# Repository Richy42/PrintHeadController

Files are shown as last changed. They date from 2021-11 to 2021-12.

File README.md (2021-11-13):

# PrintHeadController
A 3D printer controller board

Inspired by the possibility of Klipper 3D printer firmware (https://www.klipper3d.org/ ) that allows to have several I/O controller boards, PrintHeadController is a small board intended to be mounted on the moving print head assembly.

This reduces the cabling effort significantly as only power supply and USB is needed.

PrintHeadController has the following features:
* Based on the RP2040 MCU (the one that is used on the Raspberry PI Pico), so it is supported by the Klipper firmware out of the box
* Single socket for a stepper driver module e.g. DRV8825, various TMC variants
* Supports the SPI configuration of TMC drivers
* 12 V and 24 V capable
* 4 Digital inputs
* 4 MOSFET outputs (e.g. hotend heater, fans)
* 4 Thermistor inputs
* BLTouch support
* Debug pins accessible
* Accelerometer ADXL245 optional on board

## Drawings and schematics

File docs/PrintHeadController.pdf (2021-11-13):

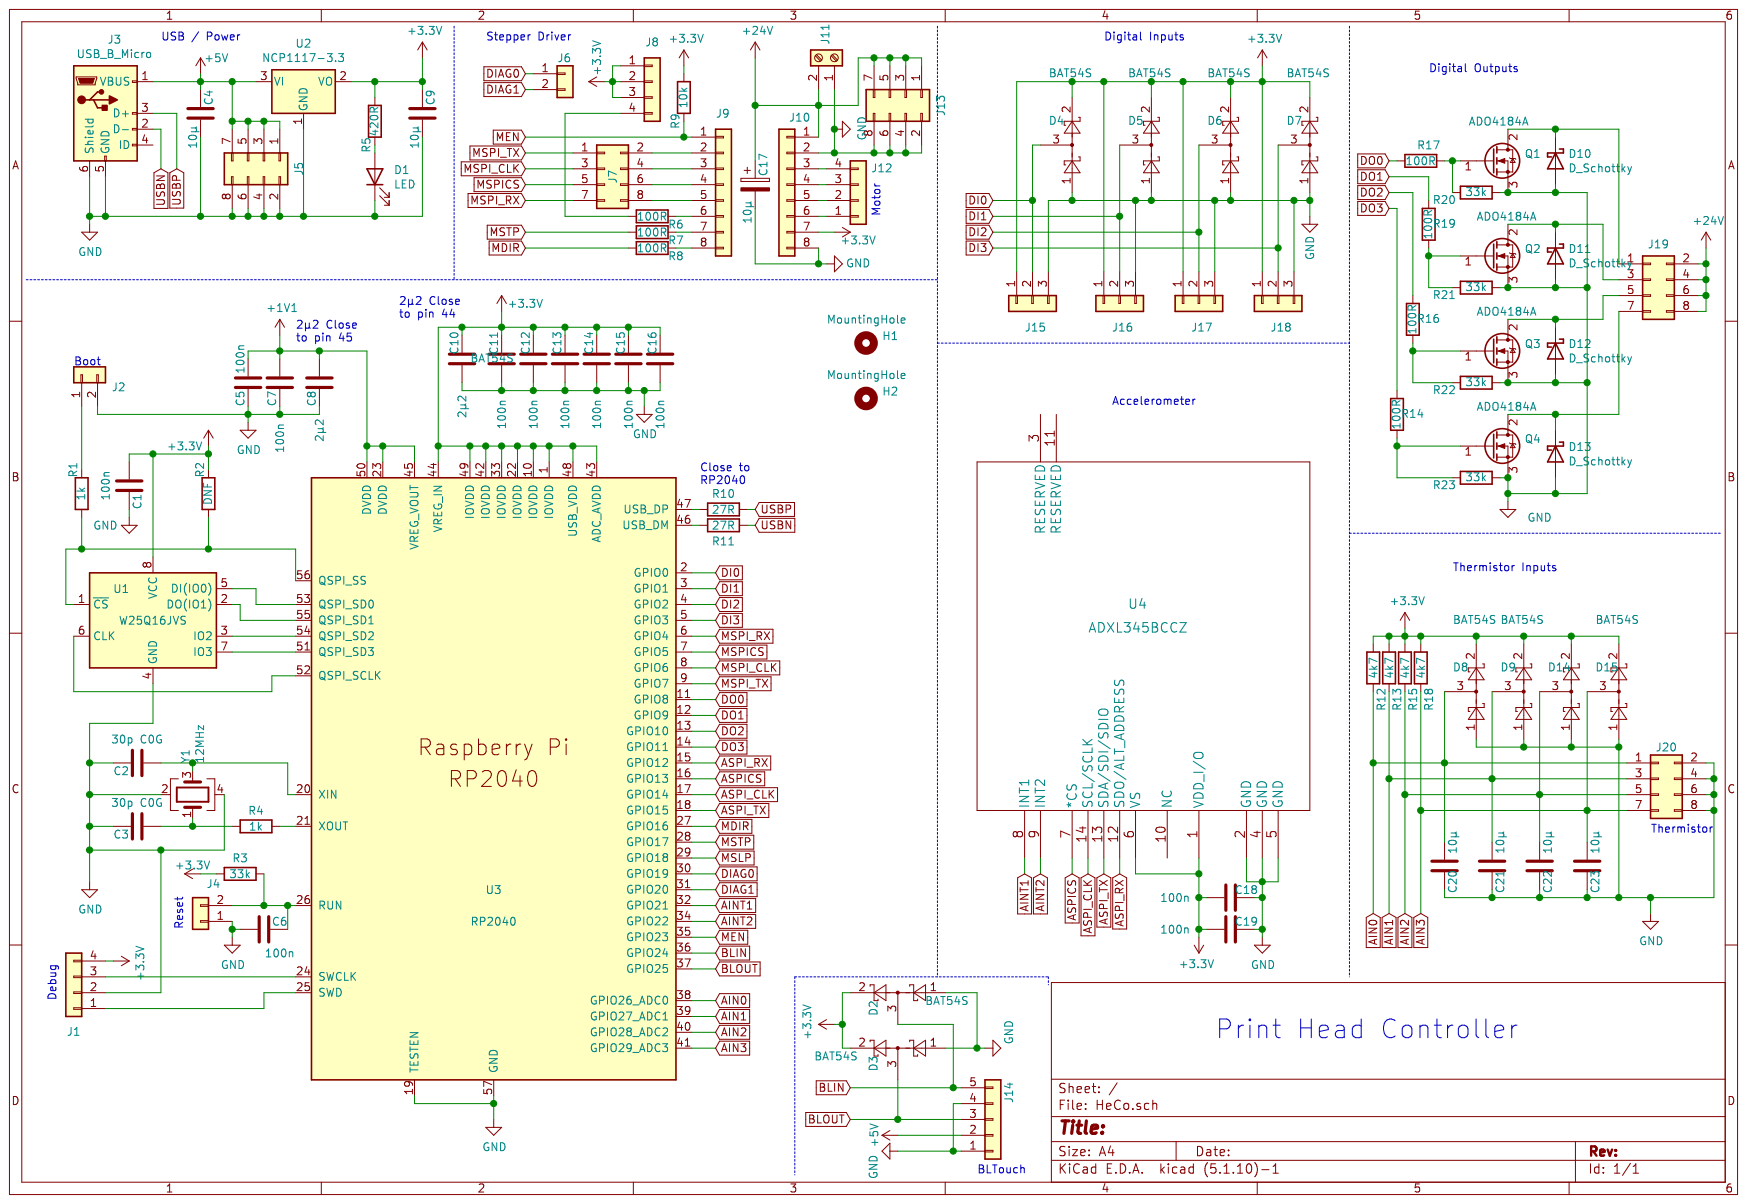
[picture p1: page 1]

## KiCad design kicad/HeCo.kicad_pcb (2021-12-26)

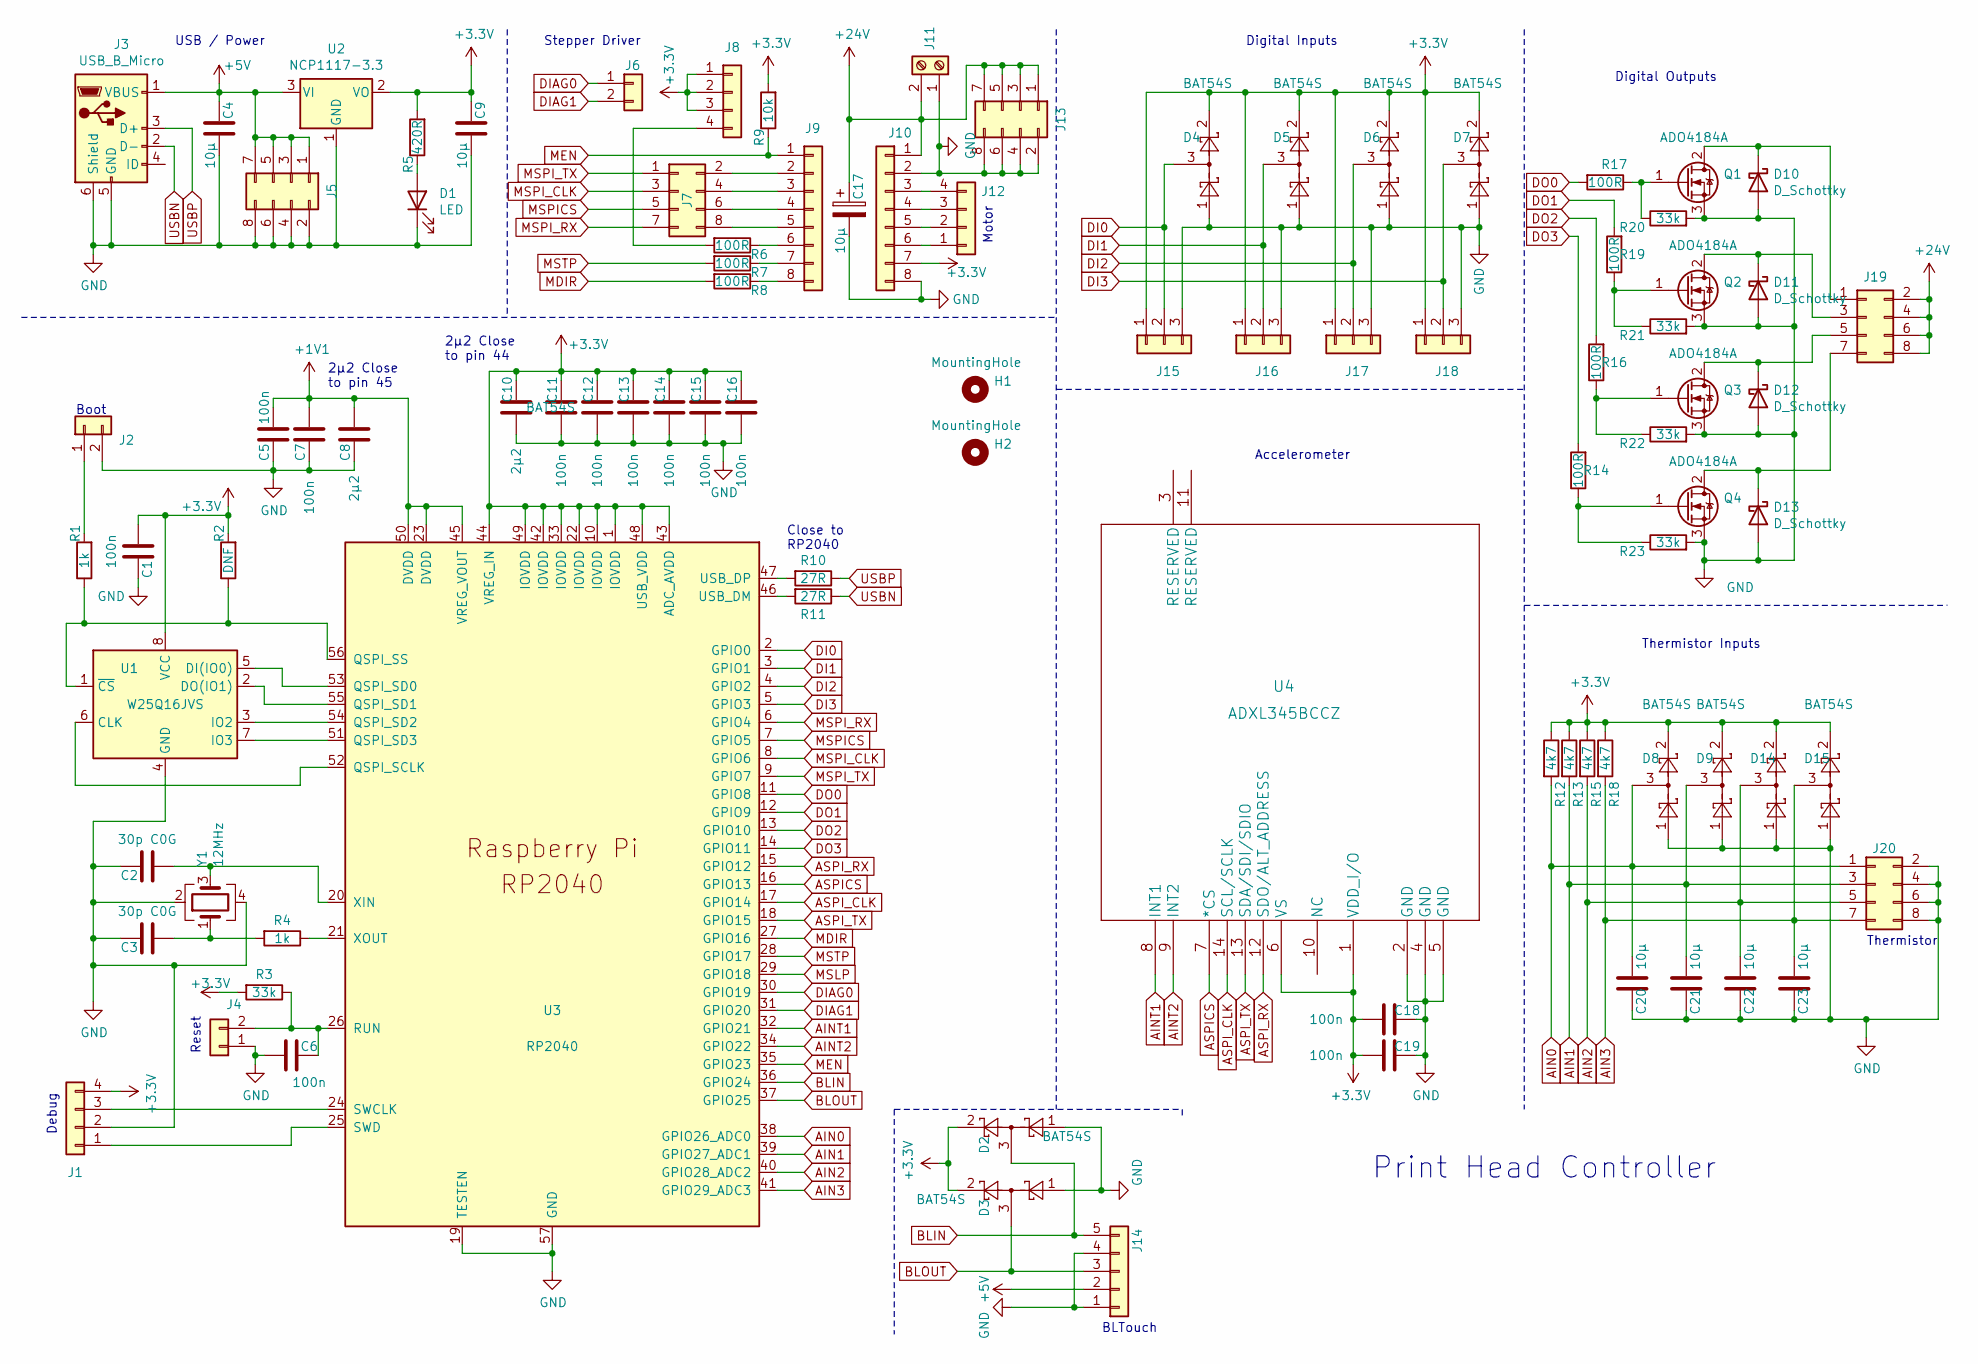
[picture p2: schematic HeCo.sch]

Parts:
C1, C5, C6, C7, C11, C12, C13, C14, C15, C16, C18, C19: 100n; C_0603_1608Metric
C2, C3: 30p C0G; C_0603_1608Metric
C4, C9, C20, C21, C22, C23: 10µ; C_0603_1608Metric
C8, C10: 2µ2; C_0603_1608Metric
C17: 10µ; CP_Elec_4x3
D1: LED; LED_0603_1608Metric
D2, D3, D4, D5, D6, D7, D8, D9, D14, D15: BAT54S; SOT-23
D10, D11, D12, D13: D_Schottky; D_0603_1608Metric
H1, H2: MountingHole; MountingHole_3.2mm_M3
J1, J8, J12: Conn_01x04; PinHeader_1x04_P2.54mm_Vertical
J2, J4: Conn_01x02; PinHeader_1x02_P2.54mm_Vertical
J3: USB_B_Micro; USB_Micro-B_Molex_47346-0001
J5, J7, J13, J19, J20: Conn_02x04_Odd_Even; PinHeader_2x04_P2.54mm_Vertical
J6: Conn_01x02; PinSocket_1x02_P2.54mm_Vertical
J9, J10: Conn_01x08; PinSocket_1x08_P2.54mm_Vertical
J11: Screw_Terminal_01x02; PhoenixContact_MSTBVA_2,5_2-G-5,08_1x02_P5.08mm_Vertical
J14: Conn_01x05; PinHeader_1x05_P2.54mm_Vertical
J15, J16, J17, J18: Conn_01x03; PinHeader_1x03_P2.54mm_Vertical
Q1, Q2, Q3, Q4: ADO4184A; TO-252-2
R1, R4: 1k; R_0603_1608Metric
R2: DNF; R_0603_1608Metric
R3, R20, R21, R22, R23: 33k; R_0603_1608Metric
R5: 420R; R_0603_1608Metric
R6, R7, R8, R14, R16, R17, R19: 100R; R_0603_1608Metric
R9: 10k; R_0603_1608Metric
R10, R11: 27R; R_0603_1608Metric
R12, R13, R15, R18: 4k7; R_0603_1608Metric
U1: W25Q16JVS; SOIC-8_5.23x5.23mm_P1.27mm
U2: NCP1117-3.3; SOT-223-3_TabPin2
U3: RP2040; RP2040-QFN-56
U4: ADXL345BCCZ
Y1: 12MHz; Crystal_SMD_3225-4Pin_3.2x2.5mm

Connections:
+1V1: C5.1, C7.1, C8.1, U3.23 (DVDD), U3.45 (VREG_VOUT), U3.50 (DVDD)
+3V3: C1.1, C9.1, C10.1, C11.1, C12.1, C13.1, C14.1, C15.1, C16.1, C18.2, C19.2, D2.2, D3.2, D4.2, D5.2, D6.2, D7.2, D8.2, D9.2, D14.2, D15.2, J1.4, J8.1, J8.2, J8.3, J10.7, J15.1, J16.1, J17.1, J18.1, R2.2, R3.2, R5.2, R9.2, R12.1, R13.1, R15.1, R18.1, U1.8 (VCC), U2.2 (VO), U3.1 (IOVDD), U3.10 (IOVDD), U3.22 (IOVDD), U3.33 (IOVDD), U3.42 (IOVDD), U3.43 (ADC_AVDD), U3.44 (VREG_IN), U3.48 (USB_VDD), U3.49 (IOVDD), U4.1 (VDD_I/O), U4.6 (VS)
+5V: C4.1, J3.1 (VBUS), J5.1, J5.3, J5.5, J5.7, J14.2, U2.3 (VI)
+24V: C17.1, J10.1, J11.2, J13.1, J13.3, J13.5, J13.7, J19.2, J19.4, J19.6, J19.8
AIN0: C20.1, D8.3, J20.1, R12.2, U3.38 (GPIO26_ADC0)
AIN1: C21.1, D9.3, J20.3, R13.2, U3.39 (GPIO27_ADC1)
AIN2: C22.1, D14.3, J20.5, R15.2, U3.40 (GPIO28_ADC2)
AIN3: C23.1, D15.3, J20.7, R18.2, U3.41 (GPIO29_ADC3)
AINT1: U3.32 (GPIO21), U4.8 (INT1)
AINT2: U3.34 (GPIO22), U4.9 (INT2)
ASPICS: U3.16 (GPIO13), U4.7 (*CS)
ASPI_CLK: U3.17 (GPIO14), U4.14 (SCL/SCLK)
ASPI_RX: U3.15 (GPIO12), U4.12 (SDO/ALT_ADDRESS)
ASPI_TX: U3.18 (GPIO15), U4.13 (SDA/SDI/SDIO)
BLIN: D2.3, J14.5, U3.36 (GPIO24)
BLOUT: D3.3, J14.3, U3.37 (GPIO25)
DI0: D4.3, J15.2, U3.2 (GPIO0)
DI1: D5.3, J16.2, U3.3 (GPIO1)
DI2: D6.3, J17.2, U3.4 (GPIO2)
DI3: D7.3, J18.2, U3.5 (GPIO3)
DIAG0: J6.1, U3.30 (GPIO19)
DIAG1: J6.2, U3.31 (GPIO20)
DO0: R17.2, U3.11 (GPIO8)
DO1: R19.2, U3.12 (GPIO9)
DO2: R16.2, U3.13 (GPIO10)
DO3: R14.2, U3.14 (GPIO11)
GND: C1.2, C2.2, C3.2, C4.2, C5.2, C6.2, C7.2, C8.2, C9.2, C10.2, C11.2, C12.2, C13.2, C14.2, C15.2, C16.2, C17.2, C18.1, C19.1, C20.2, C21.2, C22.2, C23.2, D1.1 (K), D2.1, D3.1, D4.1, D5.1, D6.1, D7.1, D8.1, D9.1, D10.2 (A), D11.2 (A), D12.2 (A), D13.2 (A), D14.1, D15.1, J1.2, J2.2, J3.5 (GND), J3.6 (Shield), J4.1, J5.2, J5.4, J5.6, J5.8, J10.2, J10.8, J11.1, J13.2, J13.4, J13.6, J13.8, J14.1, J14.4, J15.3, J16.3, J17.3, J18.3, J20.2, J20.4, J20.6, J20.8, Q1.3 (S), Q2.3 (S), Q3.3 (S), Q4.3 (S), R20.2, R21.2, R22.2, R23.2, U1.4 (GND), U2.1 (GND), U3.19 (TESTEN), U3.57 (GND), U4.2 (GND), U4.4 (GND), U4.5 (GND), Y1.2, Y1.4
MDIR: R8.2, U3.27 (GPIO16)
MEN: J9.1, R9.1, U3.35 (GPIO23)
MSPICS: J7.5, U3.7 (GPIO5)
MSPI_CLK: J7.3, U3.8 (GPIO6)
MSPI_RX: J7.7, U3.6 (GPIO4)
MSPI_TX: J7.1, U3.9 (GPIO7)
MSTP: R7.2, U3.28 (GPIO17)
unnamed: C2.1, U3.20 (XIN), Y1.3
unnamed: C3.1, R4.2, Y1.1
unnamed: C6.1, J4.2, R3.1, U3.26 (RUN)
unnamed: D1.2 (A), R5.1
unnamed: D10.1 (K), J19.1, Q1.2 (D)
unnamed: D11.1 (K), J19.3, Q2.2 (D)
unnamed: D12.1 (K), J19.5, Q3.2 (D)
unnamed: D13.1 (K), J19.7, Q4.2 (D)
unnamed: J1.1, U3.25 (SWD)
unnamed: J1.3, U3.24 (SWCLK)
unnamed: J2.1, R1.2
unnamed: J7.2, J9.2
unnamed: J7.4, J9.3
unnamed: J7.6, J9.4
unnamed: J7.8, J9.5
unnamed: J9.6, R6.1
unnamed: J9.7, R7.1
unnamed: J9.8, R8.1
unnamed: J10.3, J12.4
unnamed: J10.4, J12.3
unnamed: J10.5, J12.2
unnamed: J10.6, J12.1
unnamed: Q1.1 (G), R17.1, R20.1
unnamed: Q2.1 (G), R19.1, R21.1
unnamed: Q3.1 (G), R16.1, R22.1
unnamed: Q4.1 (G), R14.1, R23.1
unnamed: R1.1, R2.1, U1.1 (~CS), U3.56 (QSPI_SS)
unnamed: R4.1, U3.21 (XOUT)
unnamed: R10.2, U3.47 (USB_DP)
unnamed: R11.2, U3.46 (USB_DM)
unnamed: U1.2 (DO(IO1)), U3.55 (QSPI_SD1)
unnamed: U1.3 (IO2), U3.54 (QSPI_SD2)
unnamed: U1.5 (DI(IO0)), U3.53 (QSPI_SD0)
unnamed: U1.6 (CLK), U3.52 (QSPI_SCLK)
unnamed: U1.7 (IO3), U3.51 (QSPI_SD3)
USBN: J3.2 (D-), R11.1
USBP: J3.3 (D+), R10.1

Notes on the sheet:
2µ2 Close to pin 45
Close to RP2040
Boot
Debug
Thermistor
Thermistor Inputs
Digital Outputs
Digital Inputs
USB / Power
Stepper Driver
Accelerometer
BLTouch
Motor
Reset
Print Head Controller
2µ2 Close to pin 44

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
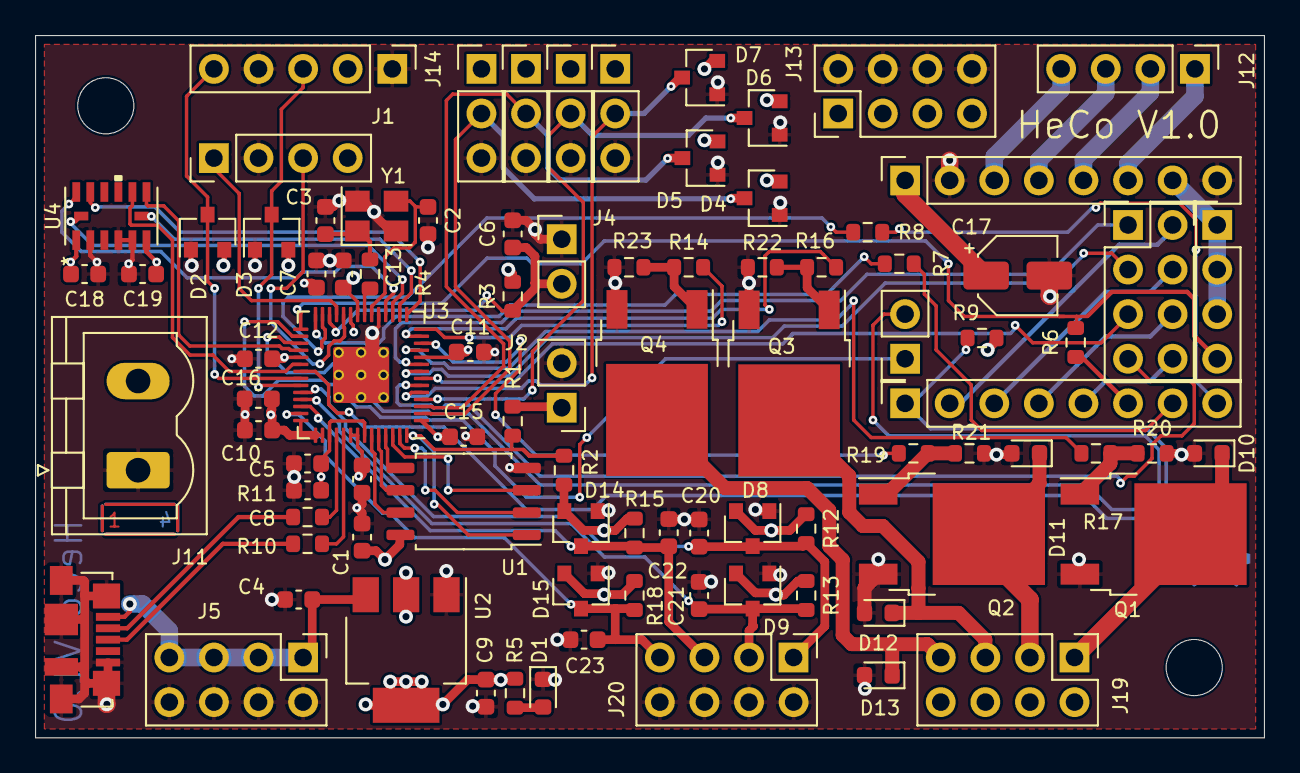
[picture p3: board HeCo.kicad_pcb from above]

Board: 4 copper layers, 70.0 x 40.0 mm, 92 parts (0 on the bottom side), 72 nets.

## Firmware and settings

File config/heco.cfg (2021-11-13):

## PrintHeadController configuration for Klipper

# This is not a full Klipper configuration.
# Copy the needed parts over to you Klipper printer.cfg

##############################################################################
## Availablle generic pins

## Thermistor Pins
#gpio26
#gpio27
#gpio28
#gpio29

## Digital Outputs
#gpio08
#gpio09
#gpio10
#gpio11

## Digital Inputs
#gpio00
#gpio01
#gpio02
#gpio03

##############################################################################


## HeCO MCU definition
[MCU heco1]
# Change the serial device according yor setup
serial: /dev/serial/by-id/usb-Klipper_rp2040_xxxxx

[extruder]
step_pin: heco1:gpio17
dir_pin: !heco1:gpio16
enable_pin: !heco1:gpio23
heater_pin: heco1:gpio08 # or any other of the digital outputs
sensor_pin: heco1:gpio26 # or any other of the thermistor inputs

[adxl345]
spi_bus:spi1a
cs_pin: heco1:gpio13
#spi_bus:
#spi_software_sclk_pin: heco1:gpio14
#spi_software_mosi_pin: heco1:gpio15
#spi_software_miso_pin: heco1:gpio12
#   See the "common SPI settings" section for a description of the
#   above parameters.


[bltouch]
sensor_pin: ^heco1:gpio24
control_pin: heco1:gpio25

# 

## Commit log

2021-11-11 pad overlaping silkscreen corrected
    [HeCo.kicad_pcb]
2021-11-13 cleanup / manufacturing files created
    [HeCo-B_Cu.gbr, HeCo-B_Mask.gbr, HeCo-B_SilkS.gbr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]
2021-11-13 Schematics pdf updated / config prepared
    [heco.cfg]
2021-11-13 initial configuration
    [heco.cfg]
2021-12-26 silk screen update
    [HeCo.kicad_pcb]

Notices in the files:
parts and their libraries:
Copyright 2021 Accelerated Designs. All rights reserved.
